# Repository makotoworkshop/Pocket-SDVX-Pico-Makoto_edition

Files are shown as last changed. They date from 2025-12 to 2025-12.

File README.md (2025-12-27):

# SDVX Pico Makoto's Édition − based on SpeedyPotato's Pocket-SDVX-Pico-v4 −
Pocket SDVX Pico Makoto's Édition source files, production files, and documentation

This work is licensed under a Creative Commons Attribution-NonCommercial-ShareAlike 4.0 International License.

- All documentation « how to » is here : https://burogu.makotoworkshop.org/index.php?pages/Menu_pocket_sdvx
- Firmware is here : https://github.com/makotoworkshop/Pico-Game-Controller-v4_Makoto-edition

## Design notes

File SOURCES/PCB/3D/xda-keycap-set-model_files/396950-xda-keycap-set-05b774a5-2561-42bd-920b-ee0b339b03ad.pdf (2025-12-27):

# XDA keycap set

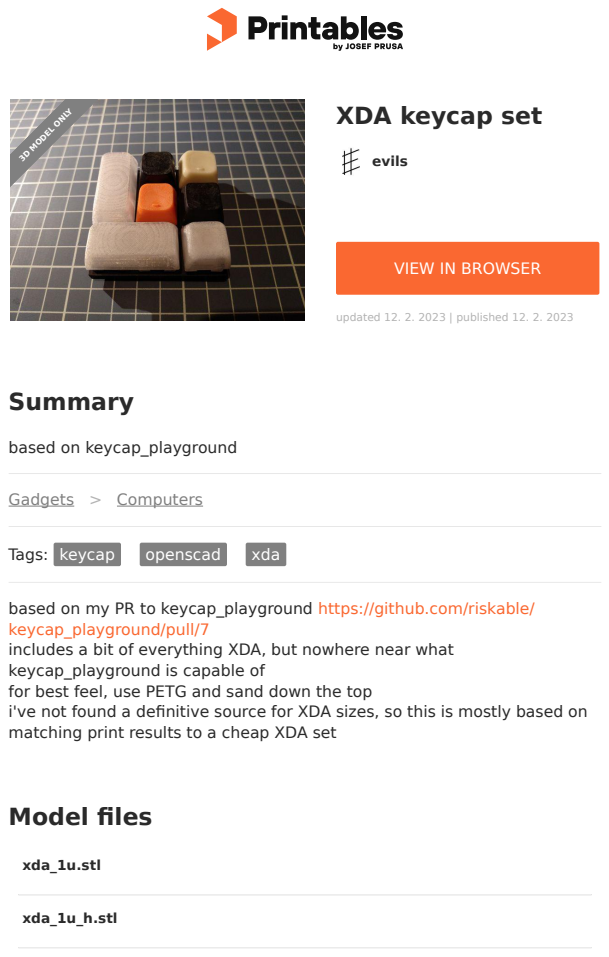
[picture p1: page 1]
Model files; Summary; based on keycap_playground; Gadgets; Computers; Tags: keycap; openscad; xda; evils; updated 12. 2. 2023 | published 12. 2. 2023; xda_1u.stl; xda_1u_h.stl; 3D MODEL ONLY

VIEW IN BROWSER (https://printables.com/model/396950-xda-keycap-set)

based on my PR to keycap_playground https://github.com/riskable/
keycap_playground/pull/7 (https://github.com/riskable/keycap_playground/pull/7)
includes a bit of everything XDA, but nowhere near what
keycap_playground is capable of
for best feel, use PETG and sand down the top
i've not found a definitive source for XDA sizes, so this is mostly based on
matching print results to a cheap XDA set

# License

This work is licensed under a

Creative Commons (4.0 International License)

Attribution-ShareAlike (http://creativecommons.org/licenses/by-sa/4.0/)

✖ | Sharing without ATTRIBUTION
✔ | Remix Culture allowed
✔ | Commercial Use

xda_125u.stl

xda_15u.stl

xda_175u.stl

xda_2u.stl

xda_2u_s.stl

xda_225u_s.stl

xda_25u_s.stl

xda_625u_s.stl

xda_7u_s.stl

xda_125u_2u_square-iso-enter.stl

xda_2u_spanning-2-switches.stl

xda_125u_fake-stepped-caps.stl

✔ | Free Cultural Works
✔ | Meets Open Definition

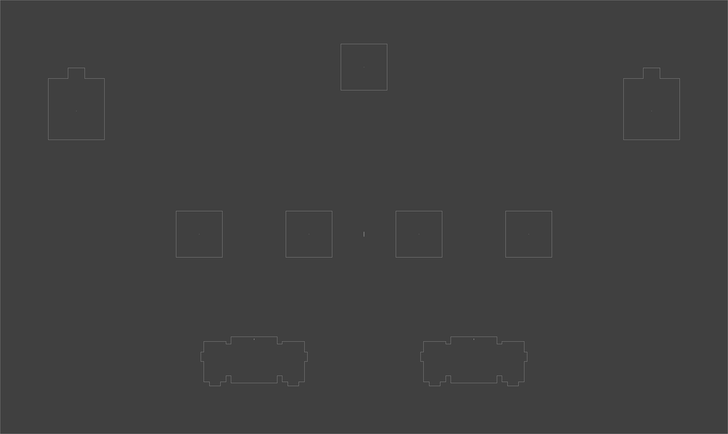
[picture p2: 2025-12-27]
SOURCES/Graphics_Kicad/skin-rgb-300dpi_MX-CUT_alpha.png

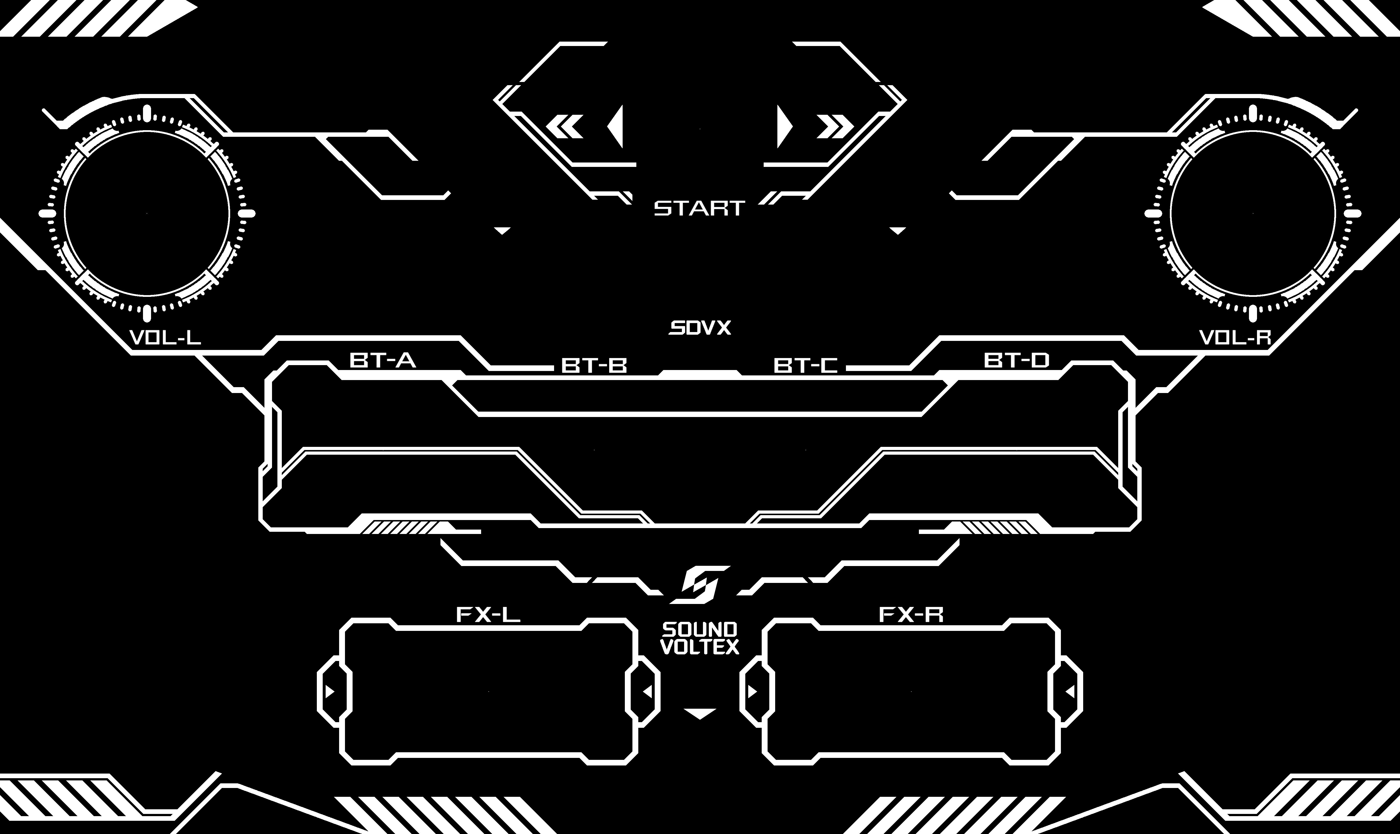
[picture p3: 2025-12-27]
SOURCES/Graphics_Kicad/skin-rgb-300dpi_SilkScreen.png

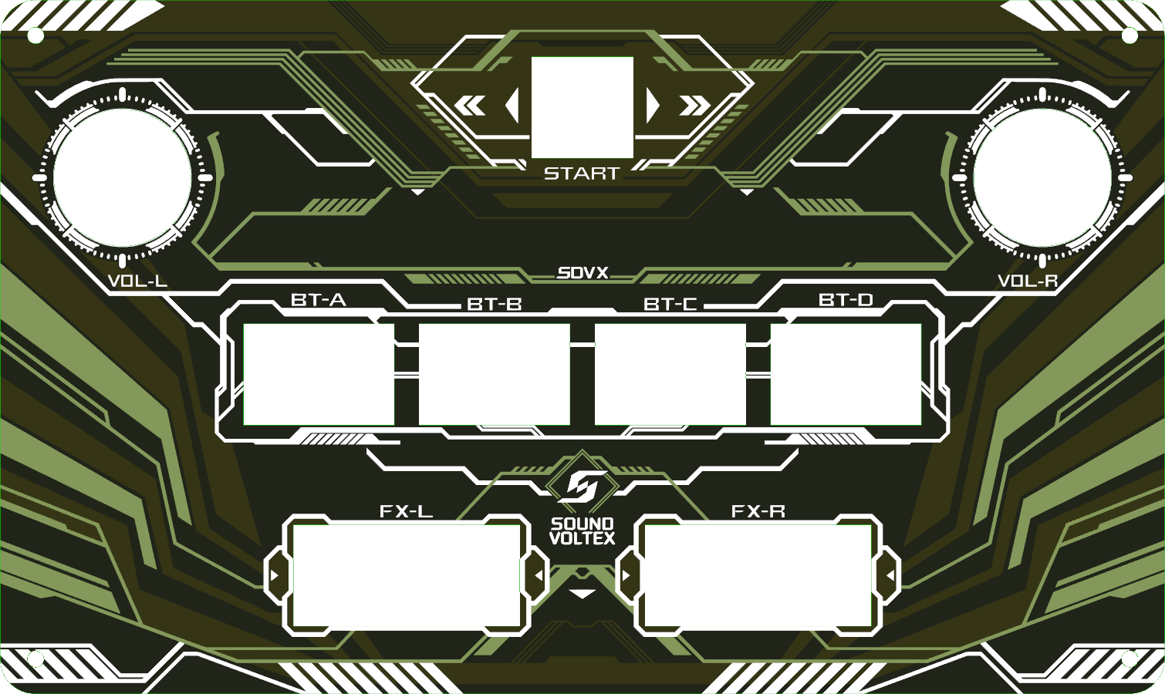
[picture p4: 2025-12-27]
SOURCES/PLATE/3D/Pocket-SDVX-Pico-Plate_Makoto_Noir.png

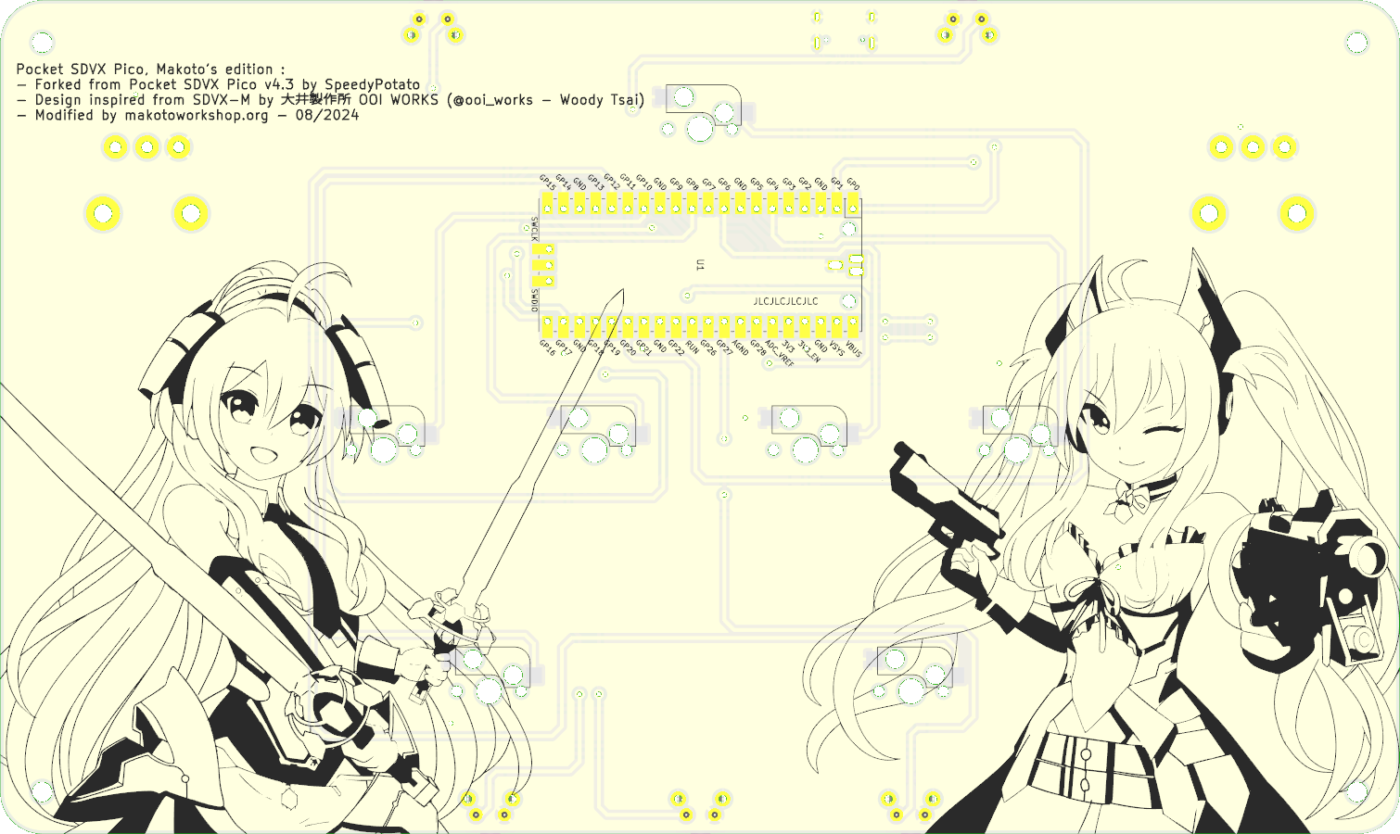
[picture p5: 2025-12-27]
SOURCES/PCB/3D/Pocket-SDVX-Pico.png

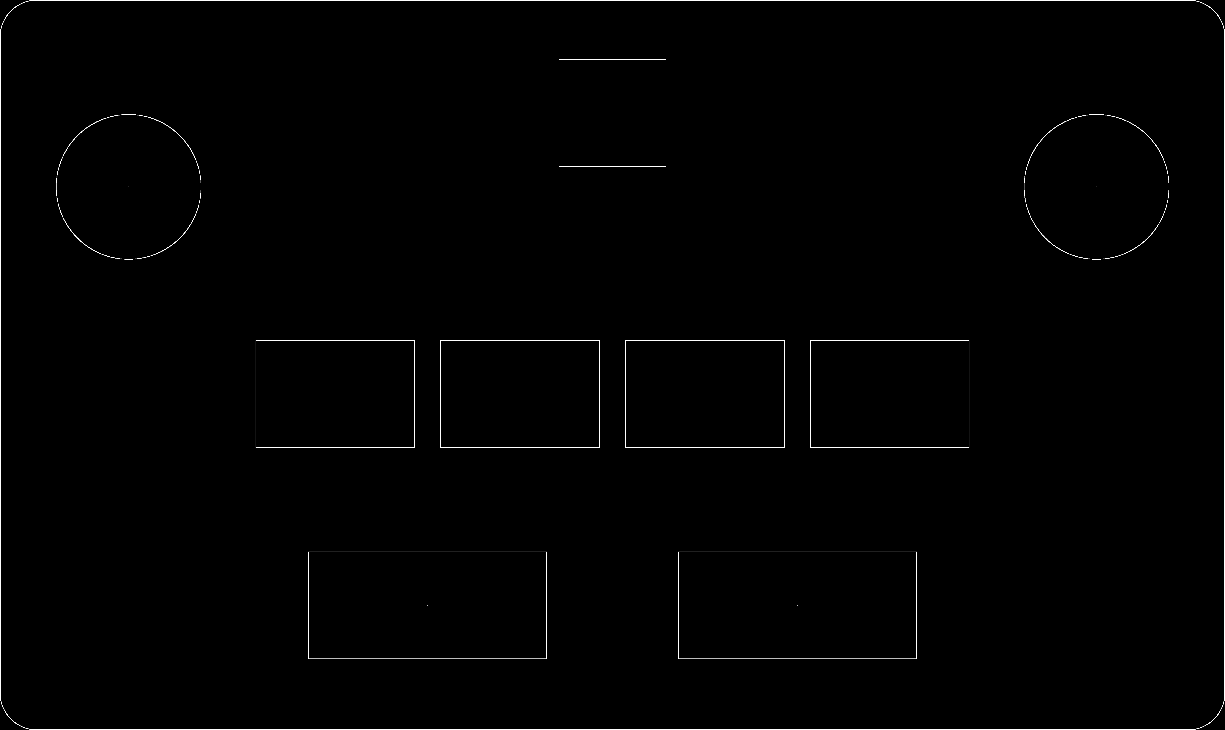
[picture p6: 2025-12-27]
SOURCES/Graphics_Kicad/skin-rgb-300dpi_EDGES-CUT.png

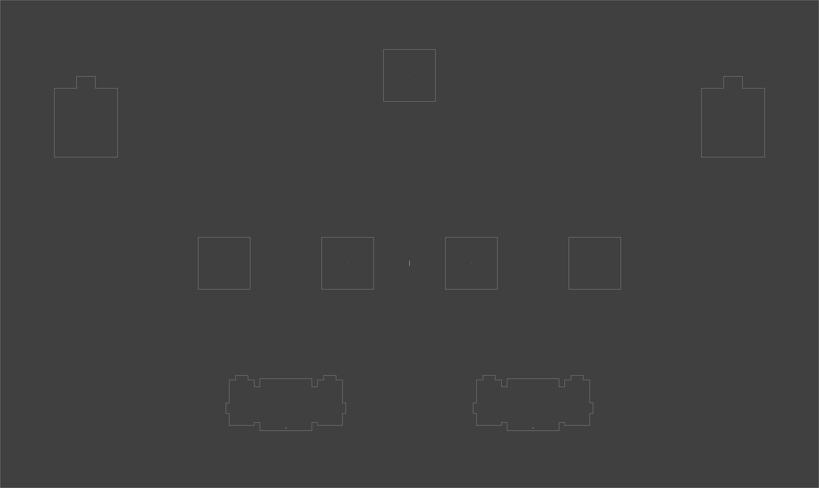
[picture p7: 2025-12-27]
SOURCES/Graphics_Kicad/skin-rgb-300dpi_MX-CUT_inverse.png

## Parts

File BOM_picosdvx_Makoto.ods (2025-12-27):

Matériel | Désignation | Boutique | QT package | QT Commande | Prix package | QT réelle | Prix Total | Prix Unitaire | QT / exemplaire | Prix / exemplaire
Embase USB-C | Type C USB 3.1 2 6 14 16 24 Pin Connector Type-C Socket SMD DIP Female Jack For PCB High Current Charging Port Transfer Data | https://www.aliexpress.com/item/1005005371954812.html | 10 | 1 | 1,37 | 10 | 1,37 | 0,137 | 1 | 0,137
Led assignables WS2812B-4020 | 20pcs/Lot WS2812B-4020 LED SMD-4020-4 Pins 12mA*3 5V RGB Full Color Chip LED High Current Side Emitting LED Beads | https://www.aliexpress.com/item/1005006302193006.html | 20 | 4 | 2,39 | 80 | 9,56 | 0,120 | 14 | 1,673
Leds 3518-1210 | 5colors each 20pcs=100PCS 3528 1210 SMD LED Kits Red Yellow Blue Green White light-emitting diode Luminescent tube | https://www.aliexpress.com/item/1005006043595920.html | 100 | 1 | 1,57 | 100 | 1,57 | 0,016 | 7 | 0,110
Cable USB-C Magnétique | USLION 540 Rotate 5A Magnetic Cable Fast Charging Type C Mirco USB Phone Data Cord For iPhone 15 14 Pro Max Xiaomi 13 POCO Redmi | https://www.aliexpress.com/item/1005005325764969.html | 1 | 1 | 1,92 | 1 | 1,92 | 1,920 | 1 | 1,920
Résistances CMS 1206 220R | 100PCS 1206 SMD 1/2W Chip Resistor 5% 0R ~ 10M 1 10R 100R 220R 330R 470R 1K 4.7K 10K 47K 100K 10 100 330 470 1M ohm Resistance | https://www.aliexpress.com/item/32982307507.html | 100 | 1 | 0,77 | 100 | 0,77 | 0,008 | 8 | 0,062
Résistances CMS 1206 5.1K | 100PCS 1206 SMD 1/2W Chip Resistor 5% 0R ~ 10M 1 10R 100R 220R 330R 470R 1K 4.7K 10K 47K 100K 10 100 330 470 1M ohm Resistance | https://www.aliexpress.com/item/32982307507.html | 100 | 1 | 0,86 | 100 | 0,86 | 0,009 | 2 | 0,017
Encodeur EC16, 24 positions | 1pc EC16 Rotary Encoder 24 Position Pulse Digital Rotary 3Pin Amplifier Volume Switch Induction Cooker Switch 15/20MM Half Shaft | https://www.aliexpress.com/item/1005005455928266.html | 1 | 10 | 1,09 | 10 | 10,9 | 1,090 | 2 | 2,180
Hot plug touche MX Gateron | Gateron Hot-swappable PCB Socket Mechanical Keyboard DIY Hot Plug Socket For Cherry MX Switch Gateron Outemu Kailh CPG151101S11 | https://www.aliexpress.com/item/1005002637150446.html | 70 | 1 | 5,94 | 70 | 5,94 | 0,085 | 7 | 0,594
Condensateurs CMS 1206 10nF | 100pcs 1206 50V SMD Thick Film l Chip Multilayer Ceramic Capacitor 1pF-100uF 10NF 100NF 1UF 2.2UF 4.7UF 10UF 1PF 6PF | https://fr.aliexpress.com/item/1005006991499257.html | 100 | 1 | 1,66 | 100 | 1,66 | 0,017 | 4 | 0,066
Condensateurs CMS 1206 100nF | 100pcs 1206 50V SMD Thick Film l Chip Multilayer Ceramic Capacitor 1pF-100uF 10NF 100NF 1UF 2.2UF 4.7UF 10UF 1PF 6PF | https://fr.aliexpress.com/item/1005006991499257.html | 100 | 1 | 1,51 | 100 | 1,51 | 0,015 | 5 | 0,076
Rpi Pico Board RP2040 | Official Raspberry Pi Pico Board RP2040 Dual-Core 264KB ARM Low-Power Microcomputers High-Performance Cortex-M0+ Processor | https://www.aliexpress.com/item/1005003939874702.html | 1 | 3 | 2,63 | 3 | 7,89 | 2,630 | 1 | 2,630
Switch micro bouton coudé | 20PCS PCB Momentary Tactile Tact Push Button Switch Right Angle With stent 6*6*4.3/5/6/7/8/9/12mm 6x6x4.3/5/6/7/8/9/12 MM | https://www.aliexpress.com/item/10000056364450.html | 20 | 2 | 1,1 | 40 | 2,2 | 0,055 | 5 | 0,275
Ventouse 25 mm à visser | 5/10Pcs 25/32/41/53mm PVC Clear Thumb Screw Clear Suction Cups White Nut Rubber Casement Suckers Rubber Screw Set Thumb Suction | https://www.aliexpress.com/item/1005004449757210.html | 10 | 2 | 2,43 | 20 | 4,86 | 0,243 | 4 | 0,972
Pieds caoutchouc | 10Pcs Black Rubber Feet Chair Floor Protector Non-slip Furniture Feet Table Leg Cover Speaker Cabinet Bottom Pad Funiture Part | https://www.aliexpress.com/item/1005005255973388.html | 10 | 2 | 2,19 | 20 | 4,38 | 0,219 | 4 | 0,876
Plaques JLCPCB | 5 plaques PCB Blanches et 5 plaques de déco noires | https://jlcpcb.com/ | 5 | 2 | 55,64 | 10 | 55,64 | 5,564 | 2 | 11,128
Switch MX Translucides x7 (noname) | MMD Ice Core Transparent Switch 5 Pins Linear Mechanical keyboard MX Switch Lubricated Clear RGB SMD For Office Switches | https://www.aliexpress.com/item/1005007199370806.html | 30 | 1 | 7,42 | 30 | 7,42 | 0,247 | 7 | 1,731
Stabilisateur MX x2 | Transparent Gold Plated Plate Mounted Stabilizer for Custom Mechanical Keyboard Plate YC66 Zeeyoo 68 YC96 Womier | https://www.aliexpress.com/item/1005004123078495.html | 8 | 1 | 6,36 | 8 | 6,36 | 0,795 | 2 | 1,590
PMMA Damengo | 5 plaques « Edge-Cut » | damengo.com sur devis | 5 | 1 | 32,95 | 5 | 32,95 | 6,59 | 1 | 6,59
Insert fileté M4 | Brass Insert Nut Hot Melt Heat Knurled Embed Injection Copper Insertnut Soldering Iron Tip 3D Print Plastic Board Nuts Inserts | https://www.aliexpress.com/item/1005007326957528.html | 100 | 1 | 3,29 | 100 | 3,29 | 0,0329 | 4 | 0,132
Insert fileté M3 | Brass Insert Nut Hot Melt Heat Knurled Embed Injection Copper Insertnut Soldering Iron Tip 3D Print Plastic Board Nuts Inserts | https://www.aliexpress.com/item/1005007326957528.html | 200 | 1 | 3,64 | 200 | 3,64 | 0,0182 | 8 | 0,146
Vise à tête plate M4 x 8 mm cruciforme | CM M1.4 M1.6 M2 M2.5 M3 M4 M5 M6 A2-70 304 Stainless Steel Cross Phillips Ultra Thin Super Low Flat Wafer Head Bolt Screw | https://www.aliexpress.com/item/4000310574303.html | 10 | 2 | 1,21 | 20 | 2,42 | 0,121 | 4 | 0,484
Vis à tête fraisées M3 x 10 mm hexagonale | WZHUIDA Hexagon Hex Socket Countersunk Flat Head Screw M2 M3 M4 M5 M6 M8 M10 Allen Bolts DIN7991 304 Stainless Steel | https://www.aliexpress.com/item/1005006180128211.html | 50 | 1 | 1,64 | 50 | 1,64 | 0,033 | 4 | 0,131
Vis à tête fraisées M3 x 8 mm hexagonale | WZHUIDA Hexagon Hex Socket Countersunk Flat Head Screw M2 M3 M4 M5 M6 M8 M10 Allen Bolts DIN7991 304 Stainless Steel | https://www.aliexpress.com/item/1005006180128211.html | 50 | 1 | 1,54 | 50 | 1,54 | 0,031 | 4 | 0,123
PMMA Damengo | 3 plaques dessous 3 mm | damengo.com sur devis | 3 | 1 | 26,82 | 3 | 26,82 | 8,94 | 1 | 8,94
PMMA Damengo | 3 plaques dessous 2 mm | damengo.com sur devis | 3 | 1 | 14 | 3 | 14 | 4,667 | 1 | 4,667
Knob x2 | 1PCS 25x22mm High-quality Aluminum Alloy Solid Knob Volume Potentiometer HIFI Audio Amplifier Knob | https://www.aliexpress.com/item/1005005936748331.html | 1 | 2 | 2,98 | 2 | 5,96 | 2,980 | 2 | 5,960
KeyCaps FX x2 2,25u | XDA Keycaps Mechanical Keyboard Keycaps PC Material Transparent Keycap 1.75 Keycap | https://www.aliexpress.com/item/1005007014967226.html | 1 | 3 | 1,53 | 3 | 4,59 | 1,530 | 2 | 3,060
KeyCaps BT x4 1,25u | XDA Keycap Mechanical Keyboard Keycaps 1.75u Blank Game Transparent Crystal Keycaps 1.25u 1.5u 2u 2.25u 6.25u | https://www.aliexpress.com/item/1005006904095121.html | 1 | 5 | 0,52+fdp | 5 | 4,75 | 0,950 | 4 | 3,800
KeyCaps Start x1 1u | 1.6mm PC XDA 2 Keycaps Mechanical Keyboard Ball Caps Gamer Transparent Crystal Keycaps Mx Switches XDA 2 Height 9.3mm | https://www.aliexpress.com/item/1005006504565661.html | 1 | 3 | 1,03 | 3 | 3,09 | 1,030 | 1 | 1,030
 |  |  |  |  | Matos | TOTAL | 229,5 | € | L’unité TOTAL | 61,10 | €

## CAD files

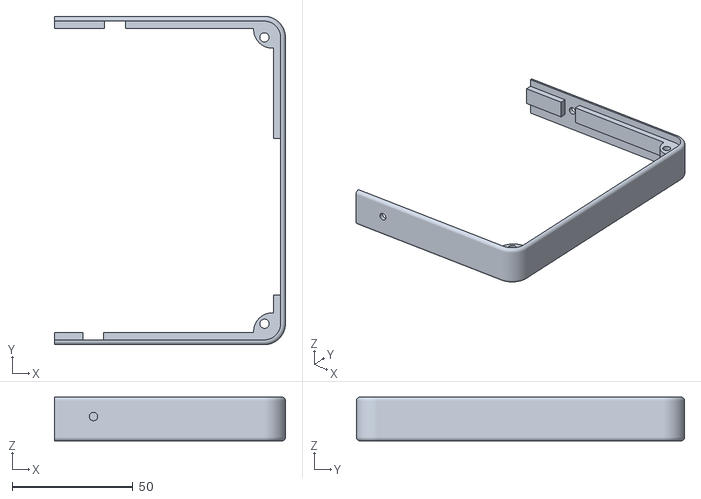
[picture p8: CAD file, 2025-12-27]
PRODUCTION/3D_printables/Contour_Cadre/Pocket-SDVX-Pico-CASE_Makoto-BoitierCut_Contour_Droit_2x3mm.stl
95.6 x 135.9 x 18.2

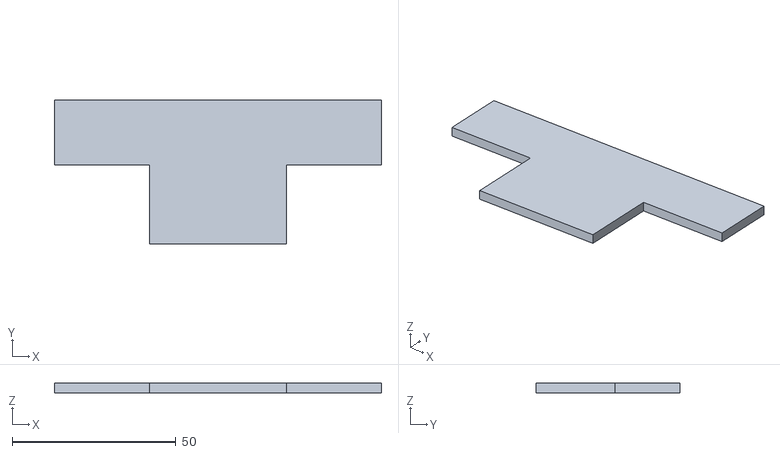
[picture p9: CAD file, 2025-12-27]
PRODUCTION/3D_printables/Plaque_Dessous_Fond/Pocket-SDVX-Pico-CASE_Makoto-BoitierPlaquettes Raccord01.stl
99.8 x 43.8 x 2.90

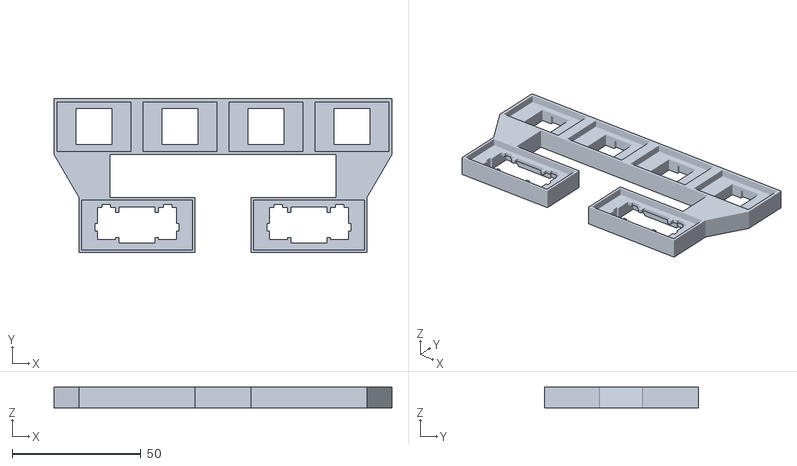
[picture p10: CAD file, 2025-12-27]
PRODUCTION/3D_printables/Supports_MX/Pocket-SDVX-Pico-CASE_Makoto_Support_6MX.stl
131.1 x 59.6 x 8.02

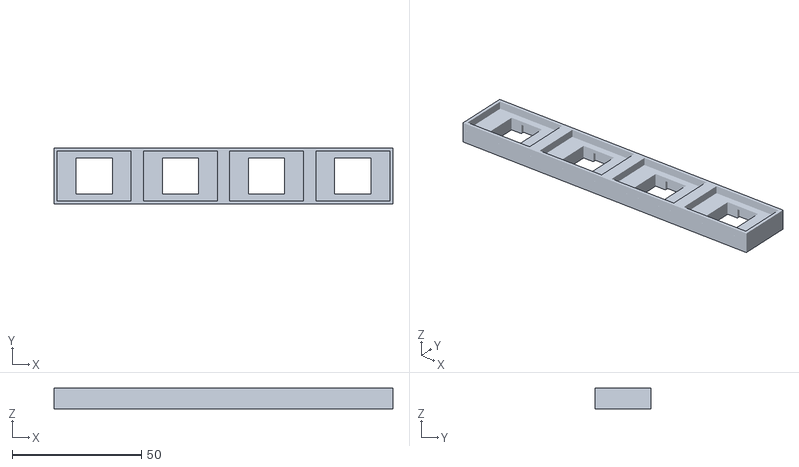
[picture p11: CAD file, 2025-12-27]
SOURCES/CASE/Pocket-SDVX-Pico-CASE_Makoto-FrameClips BT.stl
131.1 x 21.7 x 8.02

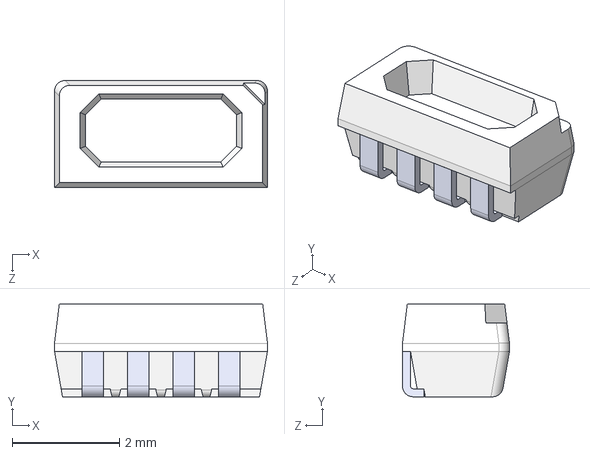
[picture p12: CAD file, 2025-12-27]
SOURCES/PCB/3D/WS2812B-4020--3DModel-STEP-269445.STEP
3.98 x 1.73 x 2.00 mm

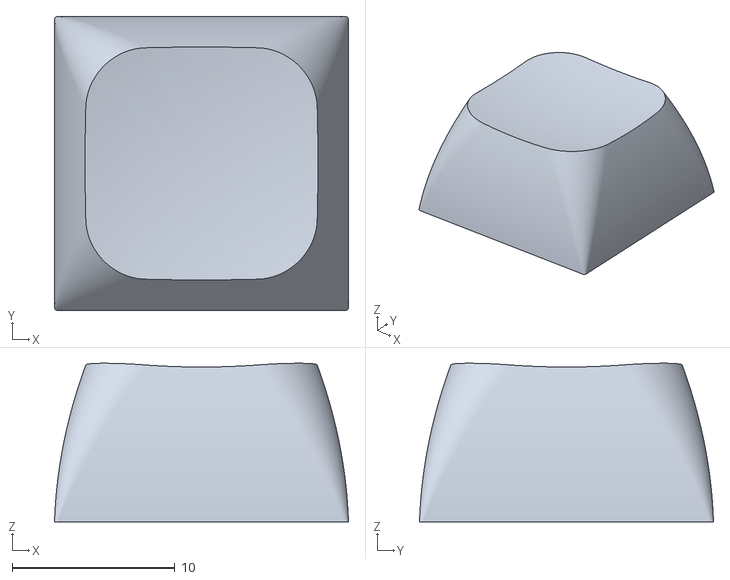
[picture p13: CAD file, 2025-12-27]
SOURCES/PCB/3D/xda-keycap-set-model_files/XDA_1U.stl
18.0 x 18.0 x 9.73

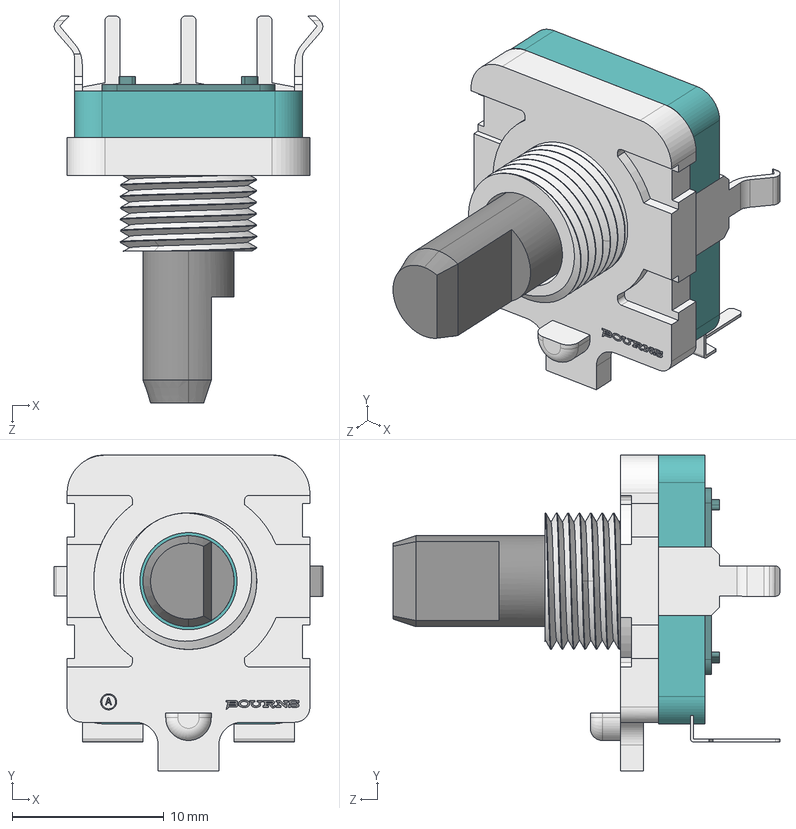
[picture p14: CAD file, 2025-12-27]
SOURCES/PCB/PEC16-4015F-N0024/3D/PEC16-4015F-N0024.stp
17.7 x 20.8 x 25.5 mm
PEC16-4X20F-SXXXX
Bourns Logo

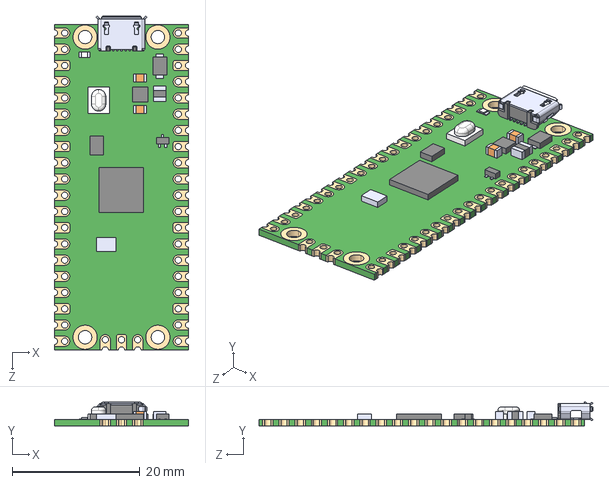
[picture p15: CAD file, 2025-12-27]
SOURCES/PCB/RP_Silicon_KiCad/KiCadLibraries/SC0915--3DModel-STEP-56544.STEP
21.0 x 3.73 x 52.3 mm

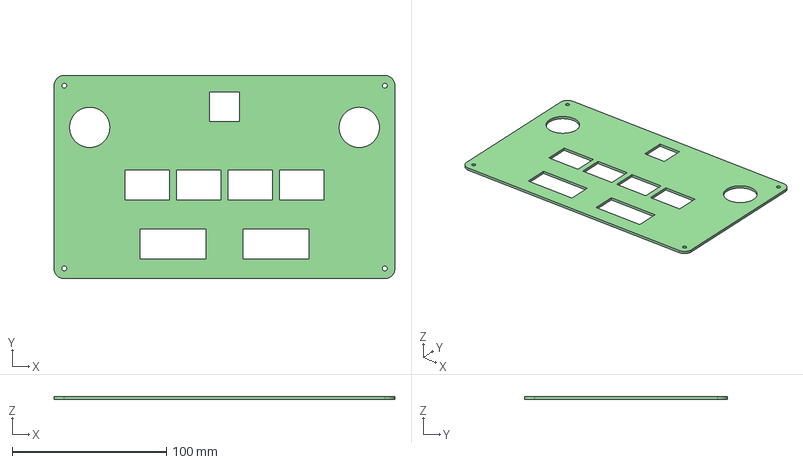
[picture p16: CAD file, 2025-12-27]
SOURCES/PLATE/3D/Pocket-SDVX-Pico-PMMA2mm_Makoto.step
220.9 x 131.7 x 2.00 mm

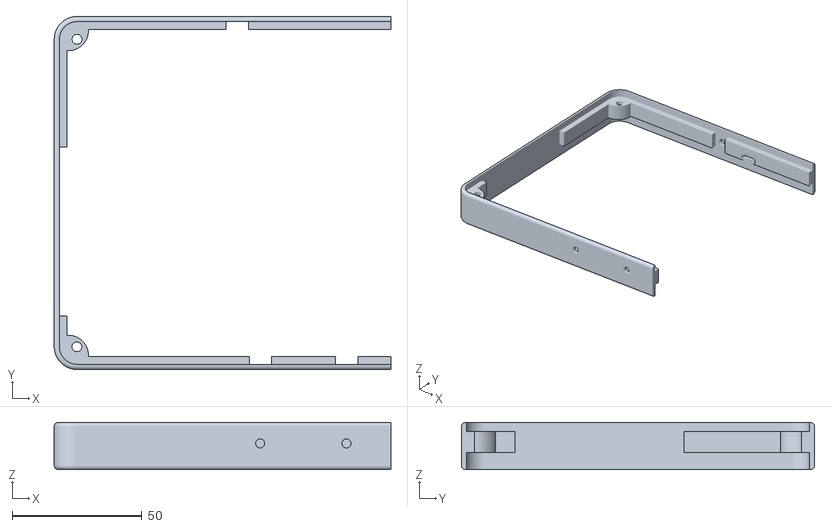
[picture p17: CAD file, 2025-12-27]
PRODUCTION/3D_printables/Contour_Cadre/Pocket-SDVX-Pico-CASE_Makoto-BoitierCut_Contour_Gauche_2x3mm.stl
129.6 x 135.9 x 18.2

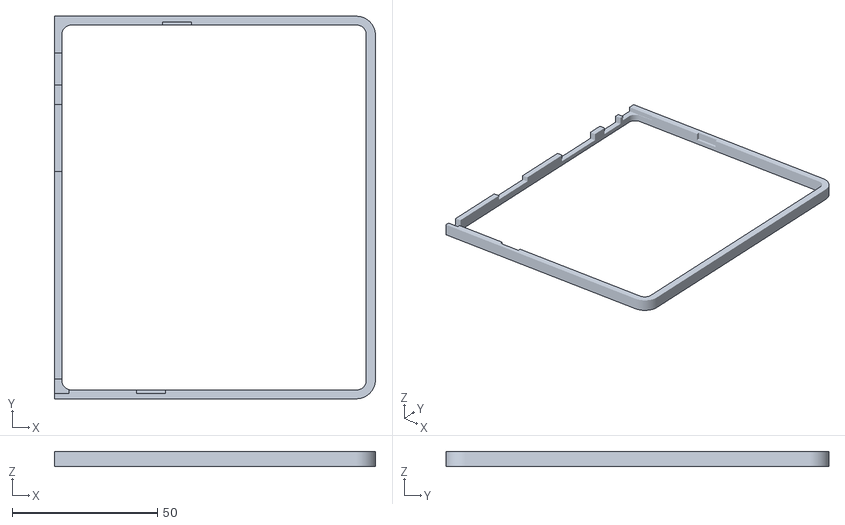
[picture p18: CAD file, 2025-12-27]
PRODUCTION/3D_printables/Plaque_Dessous_Fond/Pocket-SDVX-Pico-CASE_Makoto-BoitierCut_Fond_Gauche_test.stl
110.5 x 131.7 x 5.00

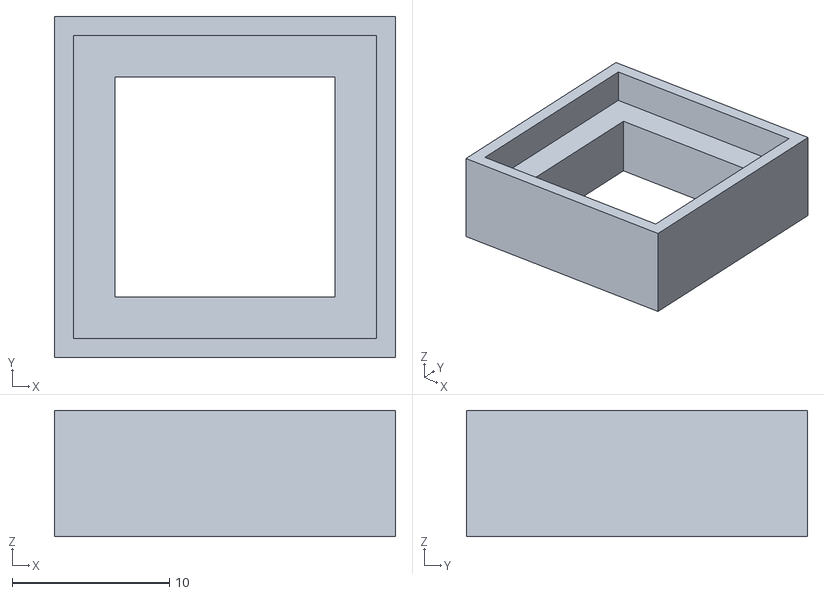
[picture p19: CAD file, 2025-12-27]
PRODUCTION/3D_printables/Supports_MX/Pocket-SDVX-Pico-CASE_Makoto-FrameClips START.stl
21.7 x 21.7 x 8.02

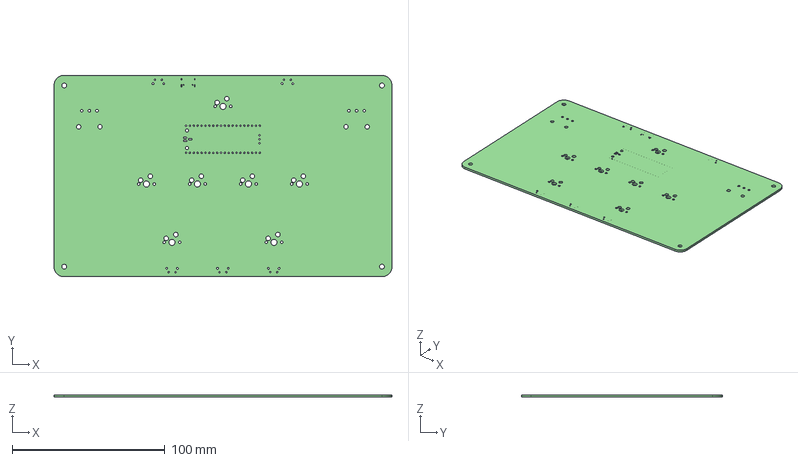
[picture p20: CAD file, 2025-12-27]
SOURCES/PCB/3D/Pocket-SDVX-Pico.step
220.9 x 131.7 x 1.60 mm

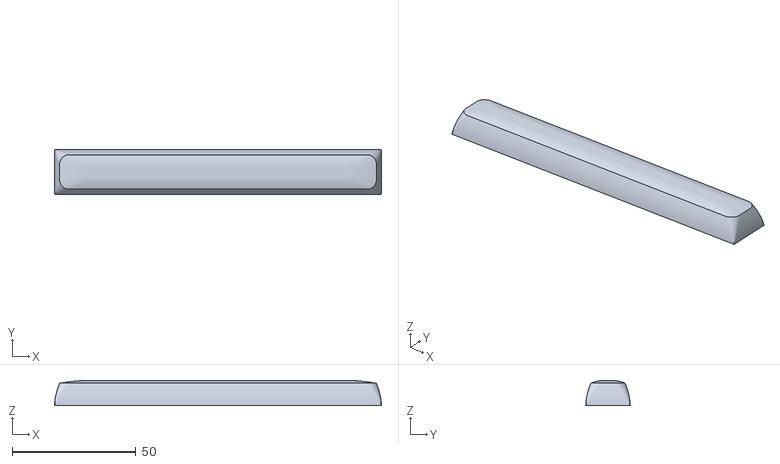
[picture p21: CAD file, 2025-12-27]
SOURCES/PCB/3D/xda-keycap-set-model_files/XDA_7U_S.stl
132.4 x 18.0 x 10.2

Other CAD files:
SOURCES/PLATE/3D/Pocket-SDVX-Pico-Plate_Makoto.step
PRODUCTION/3D_printables/Contour_Cadre/Pocket-SDVX-Pico-CASE_Makoto-BoitierCut_Contour_Gauche_3x3mm.stl
PRODUCTION/3D_printables/Plaque_Dessous_Fond/Pocket-SDVX-Pico-CASE_Makoto-BoitierCut_Fond_Gauche.stl
SOURCES/PCB/3D/xda-keycap-set-model_files/XDA_2U_spanning-2-switches.stl
PRODUCTION/3D_printables/Contour_Cadre/Pocket-SDVX-Pico-CASE_Makoto-BoitierCut_Contour_Droit_3x3mm.stl
PRODUCTION/3D_printables/Plaque_Dessous_Fond/Pocket-SDVX-Pico-CASE_Makoto-BoitierCut_Fond_Droit.stl
PRODUCTION/3D_printables/Plaque_Dessous_Fond/Pocket-SDVX-Pico-CASE_Makoto-BoitierPlaquettes Raccord02.stl
SOURCES/PCB/3D/xda-keycap-set-model_files/XDA_1.25U.stl
SOURCES/PCB/3D/xda-keycap-set-model_files/XDA_1.25U_2U_square-iso-enter.stl
SOURCES/PCB/3D/xda-keycap-set-model_files/XDA_1.25U_fake-stepped-caps.stl
SOURCES/PCB/3D/xda-keycap-set-model_files/XDA_1.5U.stl
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

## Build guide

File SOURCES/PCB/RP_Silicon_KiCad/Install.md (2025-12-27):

# Install KiCad libraries

## Manage Symbol Libraries

Accessed from the Preferences menu, add a new line with the +, give it a name and use the folder icon to point to the directory/folder where you have KiCadLibraries.

Manage Symbol Libraries screen shot


## Manage Footprint Libraries

Ditto! Accessed from the Preferences menu, add a new line with the +, give it a name and use the folder icon to point to the directory/folder where you have KiCadLibraries.

Manage Footprint Libraries screen shot


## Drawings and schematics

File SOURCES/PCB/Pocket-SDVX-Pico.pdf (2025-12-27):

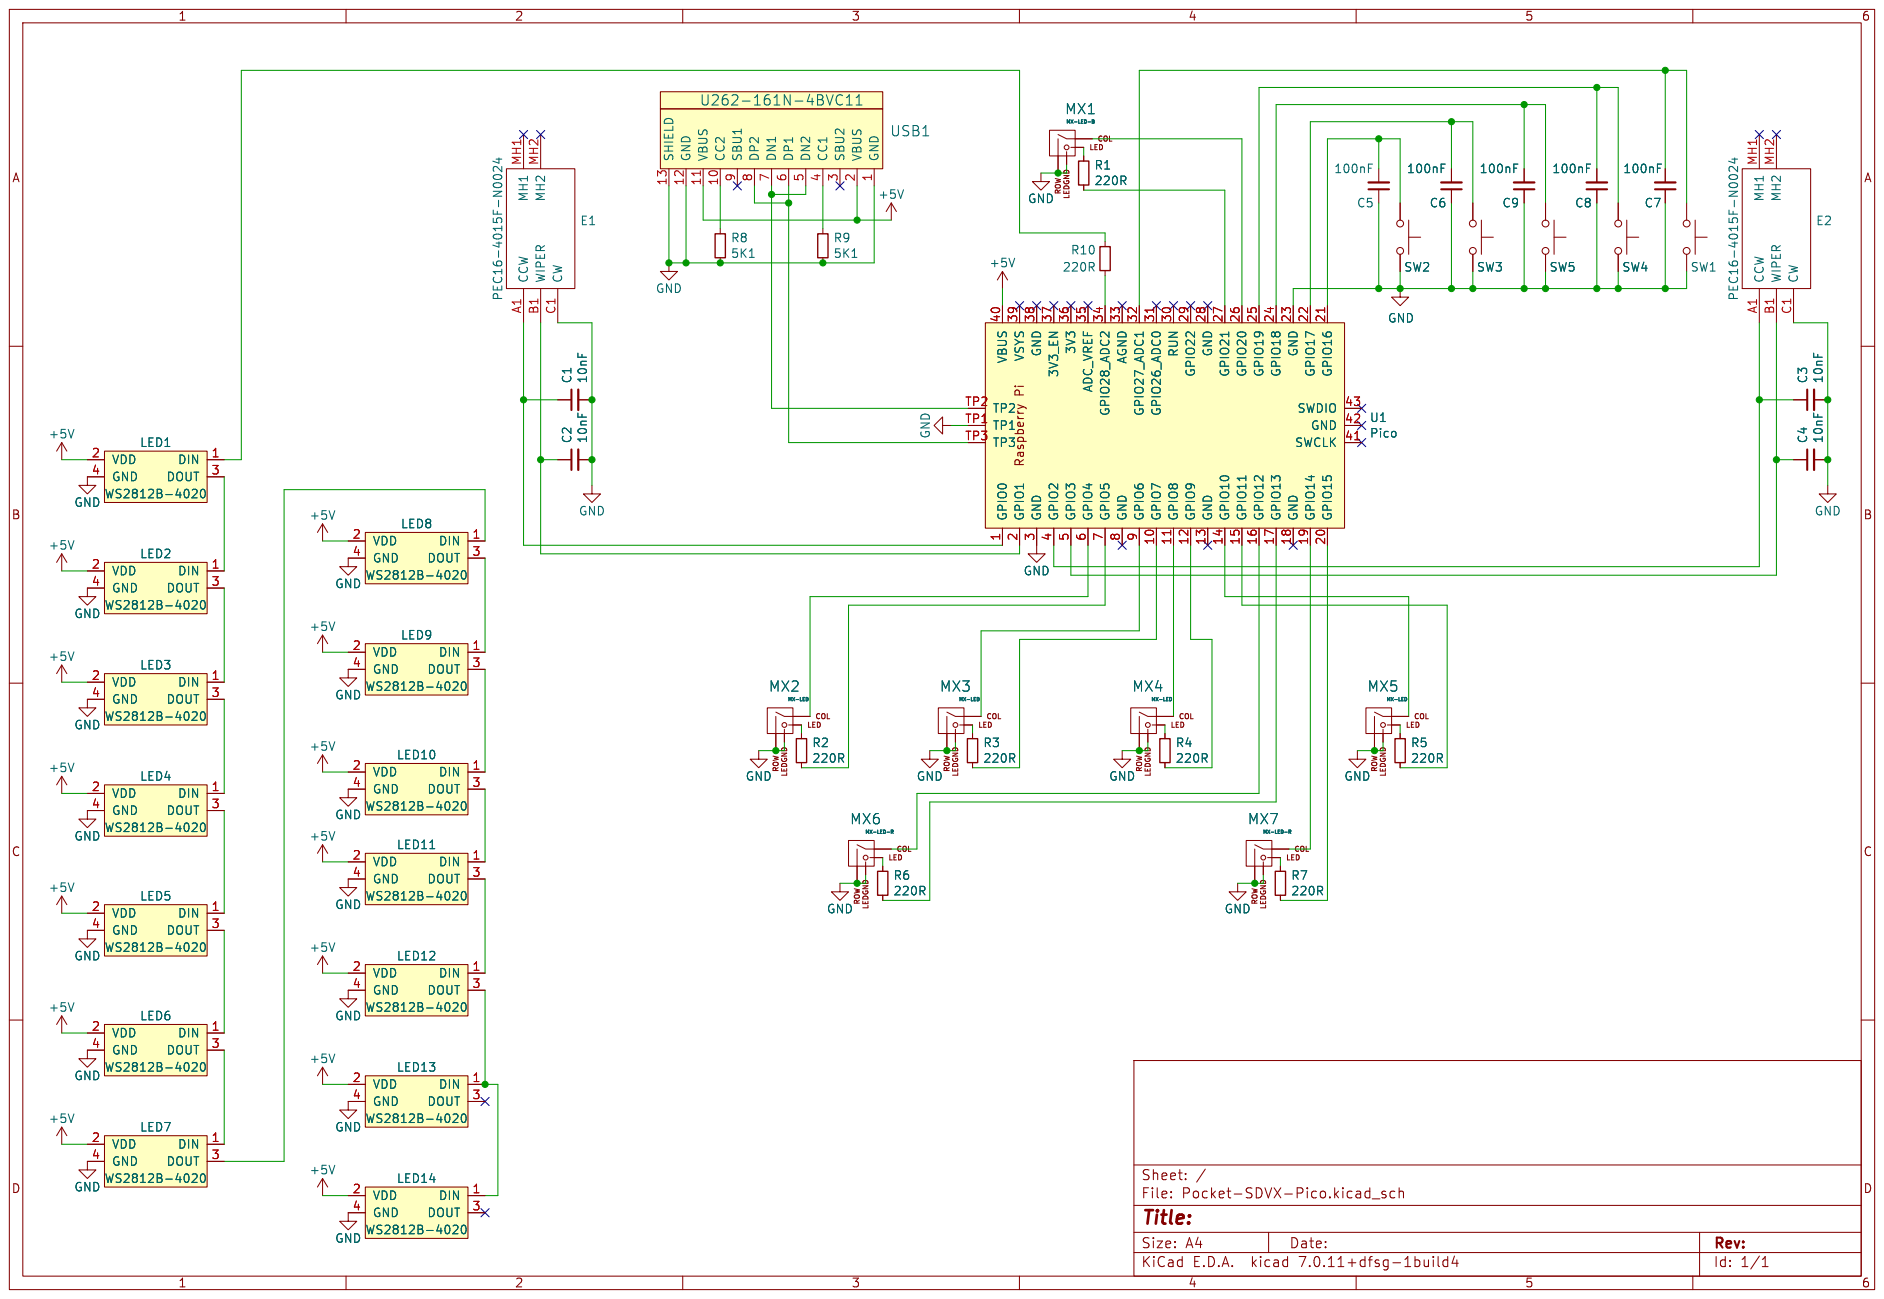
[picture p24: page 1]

Id: 1/1 Title: File: Pocket-SDVX-Pico.kicad_sch Sheet: /

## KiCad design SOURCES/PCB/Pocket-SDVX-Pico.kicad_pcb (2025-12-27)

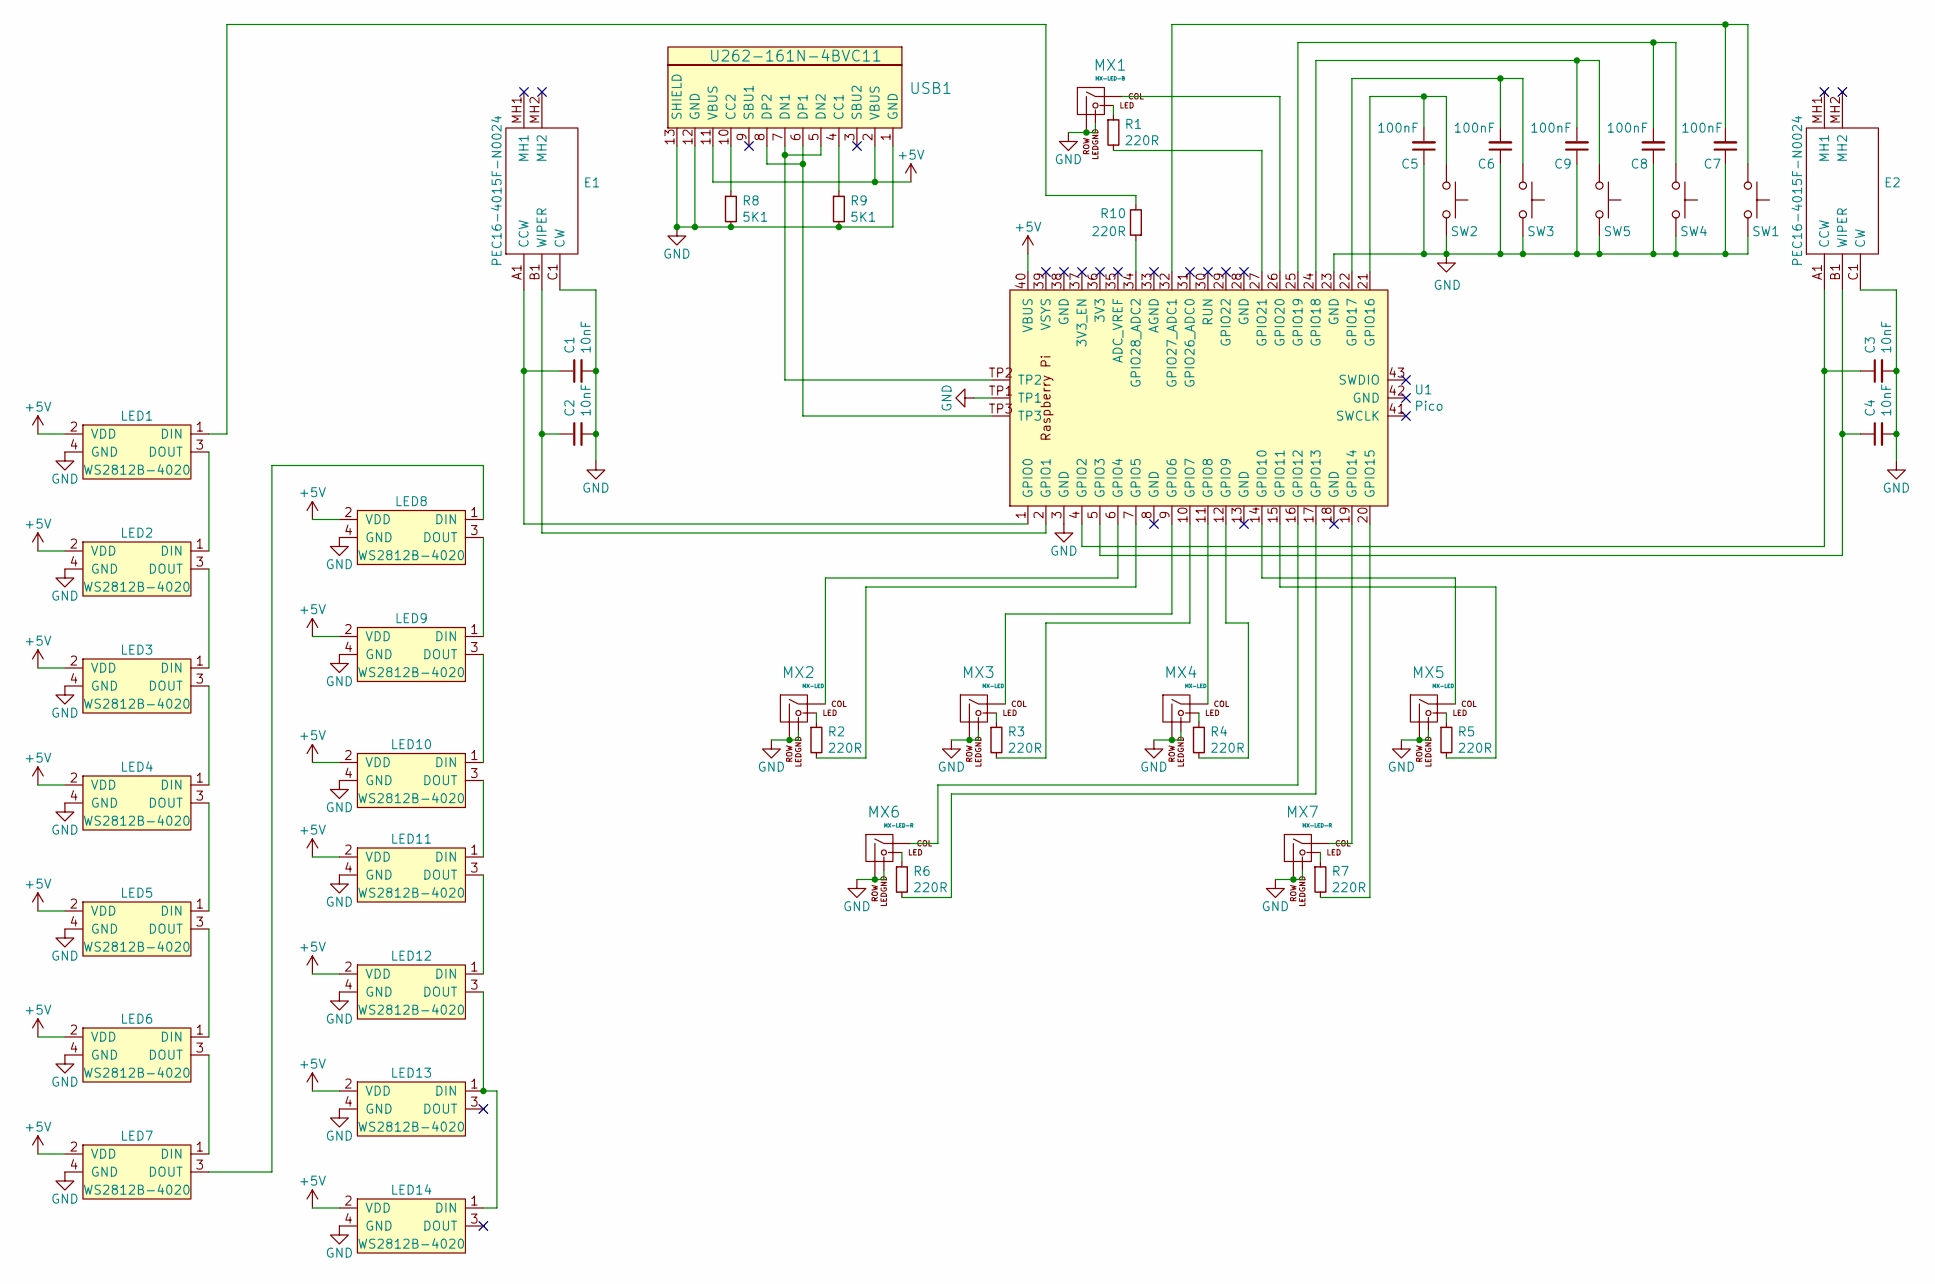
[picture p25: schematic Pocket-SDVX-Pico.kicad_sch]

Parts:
C1, C2, C3, C4: 10nF; C_1206_3216Metric_Pad1.33x1.80mm_HandSolder; LCSC C57112
C5, C6, C7, C8, C9: 100nF; C_1206_3216Metric_Pad1.33x1.80mm_HandSolder; LCSC C57112
E1, E2: PEC16-4015F-N0024; PEC16-4015F-N0024-millmax; Mouser Part Number 652-PEC16-4015FN0024
LED1, LED2, LED3, LED4, LED5, LED6, LED7, LED8, LED9, LED10, LED11, LED12, LED13, LED14: WS2812B-4020
MX1: MX-LED-B; MXOnly-1.5U-Hotswap-LED-SMD; LCSC C440444
MX2, MX3, MX4, MX5: MX-LED; MXOnly-1.5U-Hotswap-LED-SMD; LCSC C26545
MX6, MX7: MX-LED-R; MXOnly-1.5U-Hotswap-LED-SMD; LCSC C440441
R1, R2, R3, R4, R5, R6, R7, R10: 220R; R_1206_3216Metric_Pad1.30x1.75mm_HandSolder; LCSC C22962
R8, R9: 5K1; R_1206_3216Metric_Pad1.30x1.75mm_HandSolder; LCSC C23186
SW1, SW2, SW3, SW4, SW5: SW_Push; SW_Tactile_SPST_Angled_PTS645Vx83-2LFS
U1: Pico; RPi_Pico_SMD_TH
USB1: U262-161N-4BVC11; HRO-TYPE-C-31-M-12-Assembly; LCSC C319148

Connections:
+5V: LED1.2 (VDD), LED2.2 (VDD), LED3.2 (VDD), LED4.2 (VDD), LED5.2 (VDD), LED6.2 (VDD), LED7.2 (VDD), LED8.2 (VDD), LED9.2 (VDD), LED10.2 (VDD), LED11.2 (VDD), LED12.2 (VDD), LED13.2 (VDD), LED14.2 (VDD), U1.40 (VBUS), USB1.2 (VBUS), USB1.11 (VBUS)
GND: C1.2, C2.2, C3.2, C4.2, C5.1, C6.1, C7.1, C8.1, C9.1, E1.C1 (CW), E2.C1 (CW), LED1.4 (GND), LED2.4 (GND), LED3.4 (GND), LED4.4 (GND), LED5.4 (GND), LED6.4 (GND), LED7.4 (GND), LED8.4 (GND), LED9.4 (GND), LED10.4 (GND), LED11.4 (GND), LED12.4 (GND), LED13.4 (GND), LED14.4 (GND), MX1.2 (ROW), MX1.4 (LEDGND), MX2.2 (ROW), MX2.4 (LEDGND), MX3.2 (ROW), MX3.4 (LEDGND), MX4.2 (ROW), MX4.4 (LEDGND), MX5.2 (ROW), MX5.4 (LEDGND), MX6.2 (ROW), MX6.4 (LEDGND), MX7.2 (ROW), MX7.4 (LEDGND), R8.2, R9.2, SW1.2, SW2.2, SW3.2, SW4.2, SW5.2, U1.3 (GND), U1.23 (GND), U1.TP1, USB1.1 (GND), USB1.12 (GND), USB1.13 (SHIELD)
unnamed: C1.1, E1.A1 (CCW), U1.1 (GPIO0)
unnamed: C2.1, E1.B1 (WIPER), U1.2 (GPIO1)
unnamed: C3.1, E2.A1 (CCW), U1.4 (GPIO2)
unnamed: C4.1, E2.B1 (WIPER), U1.5 (GPIO3)
unnamed: LED1.1 (DIN), R10.2
unnamed: LED1.3 (DOUT), LED2.1 (DIN)
unnamed: LED2.3 (DOUT), LED3.1 (DIN)
unnamed: LED3.3 (DOUT), LED4.1 (DIN)
unnamed: LED4.3 (DOUT), LED5.1 (DIN)
unnamed: LED5.3 (DOUT), LED6.1 (DIN)
unnamed: LED6.3 (DOUT), LED7.1 (DIN)
unnamed: LED7.3 (DOUT), LED8.1 (DIN)
unnamed: LED8.3 (DOUT), LED9.1 (DIN)
unnamed: LED9.3 (DOUT), LED10.1 (DIN)
unnamed: LED10.3 (DOUT), LED11.1 (DIN)
unnamed: LED11.3 (DOUT), LED12.1 (DIN)
unnamed: LED12.3 (DOUT), LED13.1 (DIN), LED14.1 (DIN)
unnamed: MX1.1 (COL), U1.26 (GPIO20)
unnamed: MX1.3 (LED), R1.1
unnamed: MX2.1 (COL), U1.6 (GPIO4)
unnamed: MX2.3 (LED), R2.1
unnamed: MX3.1 (COL), U1.9 (GPIO6)
unnamed: MX3.3 (LED), R3.1
unnamed: MX4.1 (COL), U1.11 (GPIO8)
unnamed: MX4.3 (LED), R4.1
unnamed: MX5.1 (COL), U1.14 (GPIO10)
unnamed: MX5.3 (LED), R5.1
unnamed: MX6.1 (COL), U1.16 (GPIO12)
unnamed: MX6.3 (LED), R6.1
unnamed: MX7.1 (COL), U1.19 (GPIO14)
unnamed: MX7.3 (LED), R7.1
unnamed: R2.2, U1.7 (GPIO5)
unnamed: R3.2, U1.10 (GPIO7)
unnamed: R4.2, U1.12 (GPIO9)
unnamed: R5.2, U1.15 (GPIO11)
unnamed: R6.2, U1.17 (GPIO13)
unnamed: R7.2, U1.20 (GPIO15)
unnamed: C5.2, SW2.1, U1.21 (GPIO16)
unnamed: C6.2, SW3.1, U1.22 (GPIO17)
unnamed: C9.2, SW5.1, U1.24 (GPIO18)
unnamed: C8.2, SW4.1, U1.25 (GPIO19)
unnamed: R1.2, U1.27 (GPIO21)
unnamed: C7.2, SW1.1, U1.32 (GPIO27_ADC1)
unnamed: R10.1, U1.34 (GPIO28_ADC2)
unnamed: R9.1, USB1.4 (CC1)
unnamed: R8.1, USB1.10 (CC2)
unnamed: U1.TP2, USB1.5 (DN2), USB1.7 (DN1)
unnamed: U1.TP3, USB1.6 (DP1), USB1.8 (DP2)

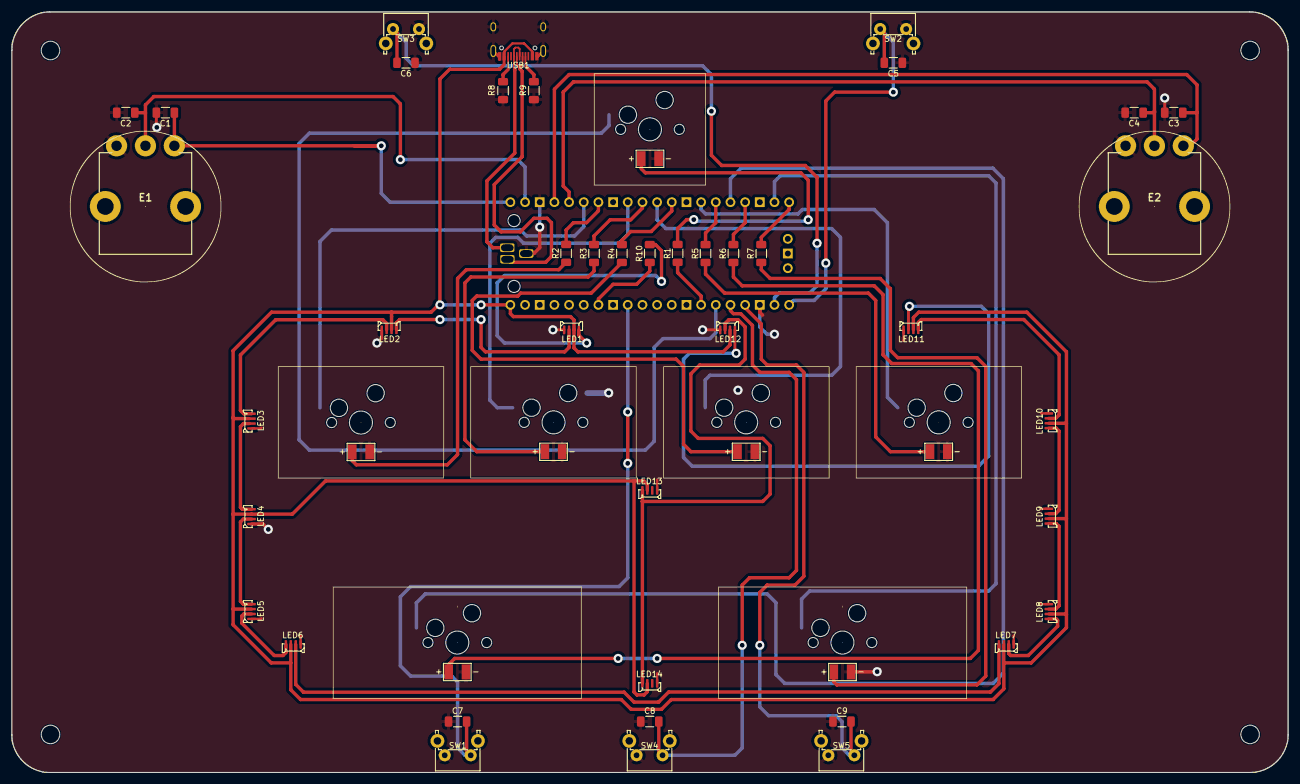
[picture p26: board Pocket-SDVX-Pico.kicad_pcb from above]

Board: 2 copper layers, 220.9 x 131.7 mm, 49 parts (1 on the bottom side), 50 nets.
